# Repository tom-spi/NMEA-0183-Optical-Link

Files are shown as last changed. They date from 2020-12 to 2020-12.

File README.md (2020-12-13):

# NMEA-0183-Optical-Link
FdEng Marine Electrical &amp; Electronic: Final Project. NMEA 0183 multiplexed fiber optic link. 
# Abstract
The standardised protocol between navigation & communication equipment on board merchant vessels is NMEA 0183. The NMEA 0183 protocol utilises the TIA/EIA 422-B serial data standard as its transmission medium [1]. The TIA/EIA 422-B standard (Commonly referred to as RS422), is a balanced double-current interchange circuit that supports data rates of up to 10Mbit/s [2]. The electrical configuration of RS422 employs a matched twisted pair that can support wire lengths of up to 4Km. In practice, shielded data cable (CAT5 STP & above) is commonly employed which offers good noise immunity to some extent. The effective noise immunity and long transmission distances can only be achieved given correct termination and separation from EMI & noise sources. 

On board a vessel, there may be a need to run long lengths of NMEA (or any RS422/485 type protocol) through areas of high EMI or electrical noise. For example, a transducer mounted on the aft of the vessel may have to run its NMEA cable(s) via the engine room to reach the bridge, this may pass through switchboard rooms, converter rooms and may also be run alongside or very close to high voltage conductors. All these areas can pose challenges due to the high levels of electrical noise and EMI. 

Utilising an optical based link means the transmission medium for the NMEA data is completely immune to any sources of noise, meaning the optical cable can be run alongside any other conductor. This can reduce costs by eliminating the need for extra deck/bulkhead penetrations, fire rated glands and additional time needed to implement the segregation of power and data conductors. Along with this, the fibre can be used as a “backbone”, carrying multiple NMEA sentences down a single fibre, eliminating the need to run multiple fibres or multiple STP cables. This can be particularly useful in a situation where there is a cluster of NMEA devices located a considerable distance from the bridge (i.e. up forward or up mast). Additionally, there is no possibility of ground loops across the optical link and the NMEA devices at each end of the optical link can be considered to be optically isolated from one another.

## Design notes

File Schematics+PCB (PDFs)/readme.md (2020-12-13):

Folder contains pdf files of schematics and PCB layers for all PCBs.

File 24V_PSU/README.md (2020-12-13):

An isolated 24v PSU was assembled utilising an off the shelf isolated power supply module.

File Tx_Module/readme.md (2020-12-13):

This folder contains the KiCAD files, PCB Gerber files and software written for the Tx Module.

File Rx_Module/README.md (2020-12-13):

This folder contains the KiCAD files, PCB Gerber files and software written for the Rx Module.

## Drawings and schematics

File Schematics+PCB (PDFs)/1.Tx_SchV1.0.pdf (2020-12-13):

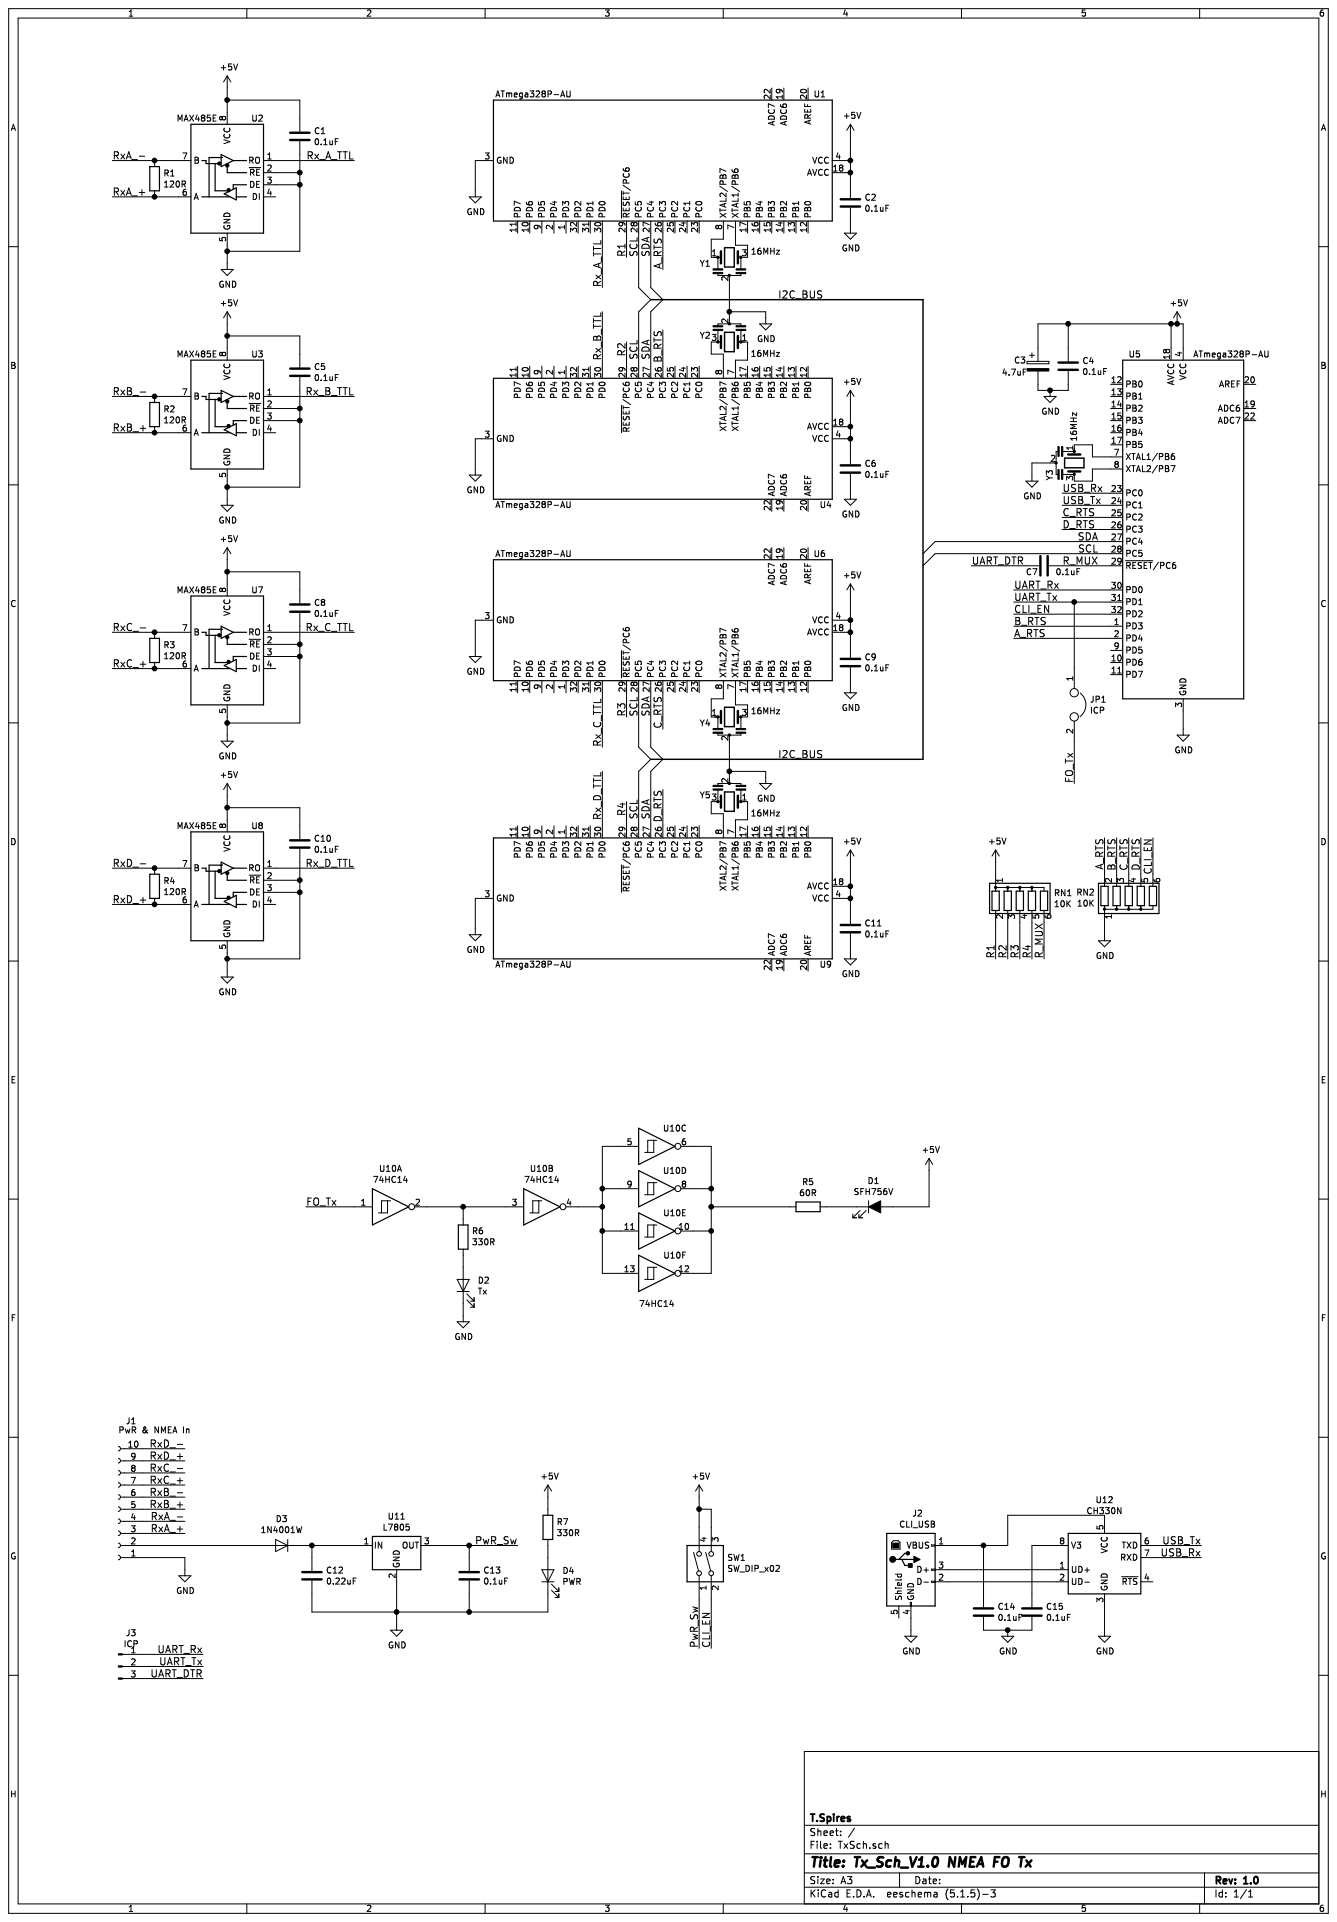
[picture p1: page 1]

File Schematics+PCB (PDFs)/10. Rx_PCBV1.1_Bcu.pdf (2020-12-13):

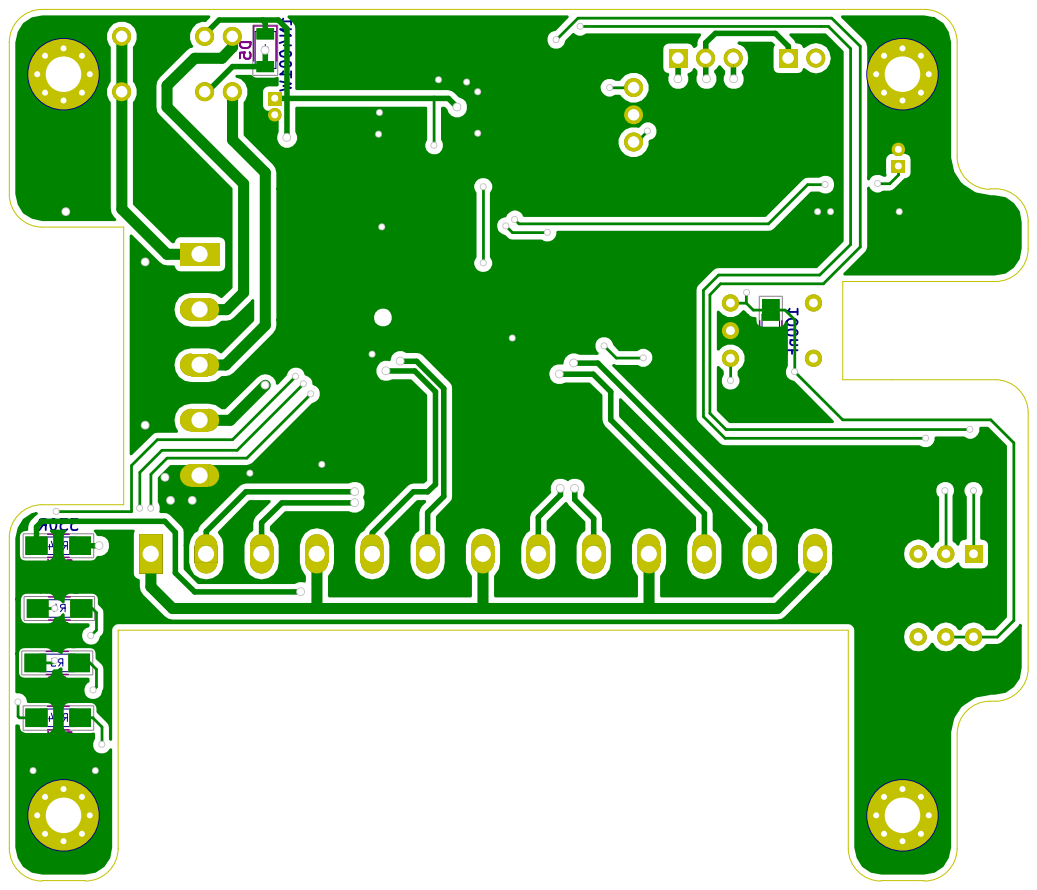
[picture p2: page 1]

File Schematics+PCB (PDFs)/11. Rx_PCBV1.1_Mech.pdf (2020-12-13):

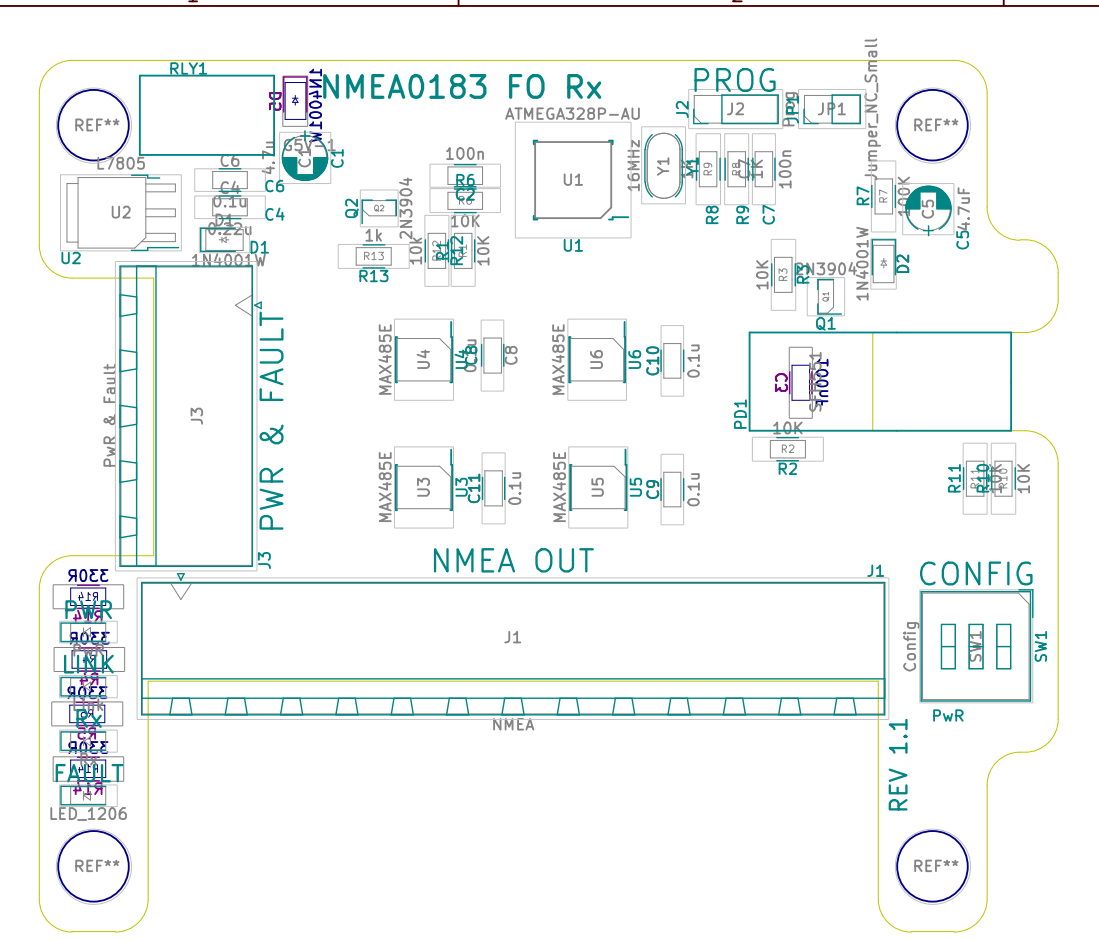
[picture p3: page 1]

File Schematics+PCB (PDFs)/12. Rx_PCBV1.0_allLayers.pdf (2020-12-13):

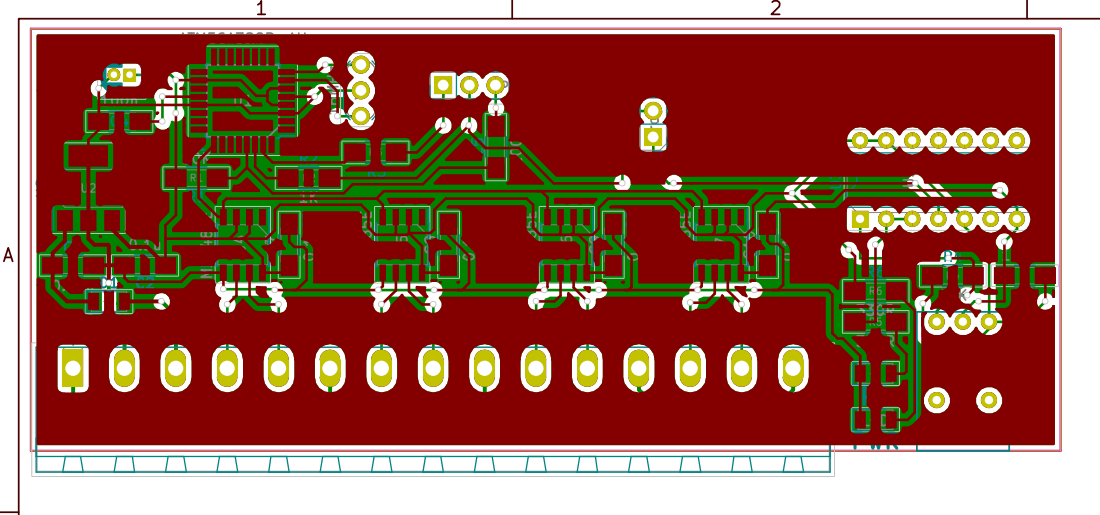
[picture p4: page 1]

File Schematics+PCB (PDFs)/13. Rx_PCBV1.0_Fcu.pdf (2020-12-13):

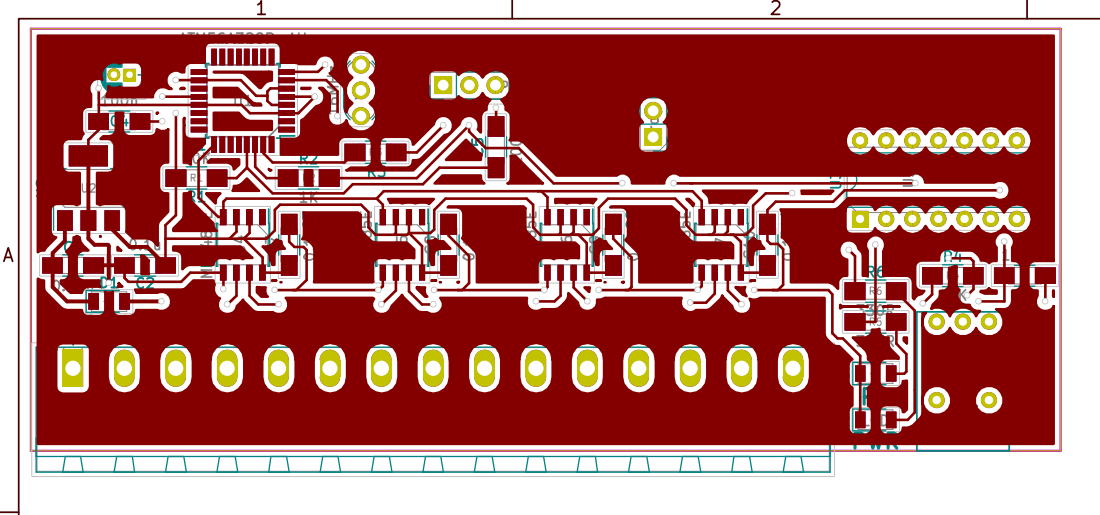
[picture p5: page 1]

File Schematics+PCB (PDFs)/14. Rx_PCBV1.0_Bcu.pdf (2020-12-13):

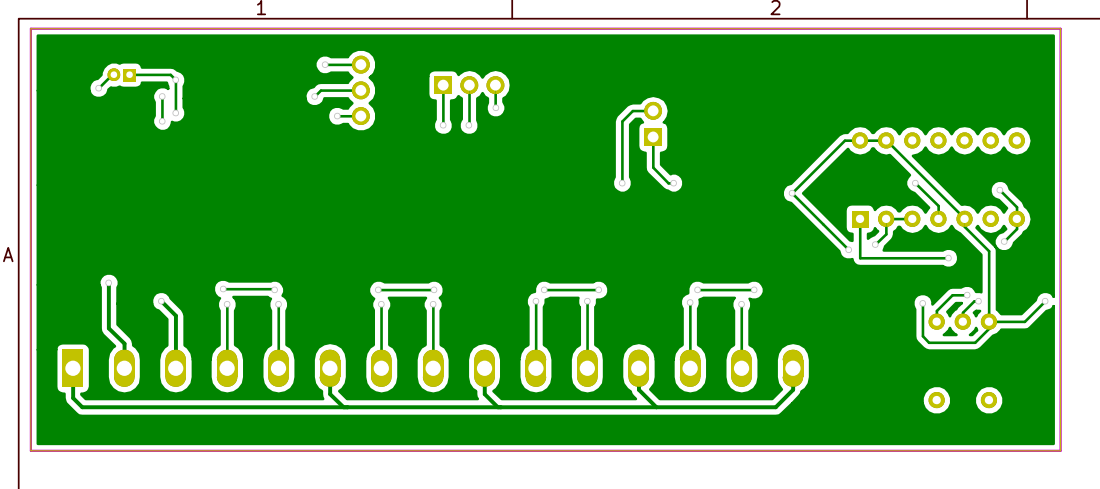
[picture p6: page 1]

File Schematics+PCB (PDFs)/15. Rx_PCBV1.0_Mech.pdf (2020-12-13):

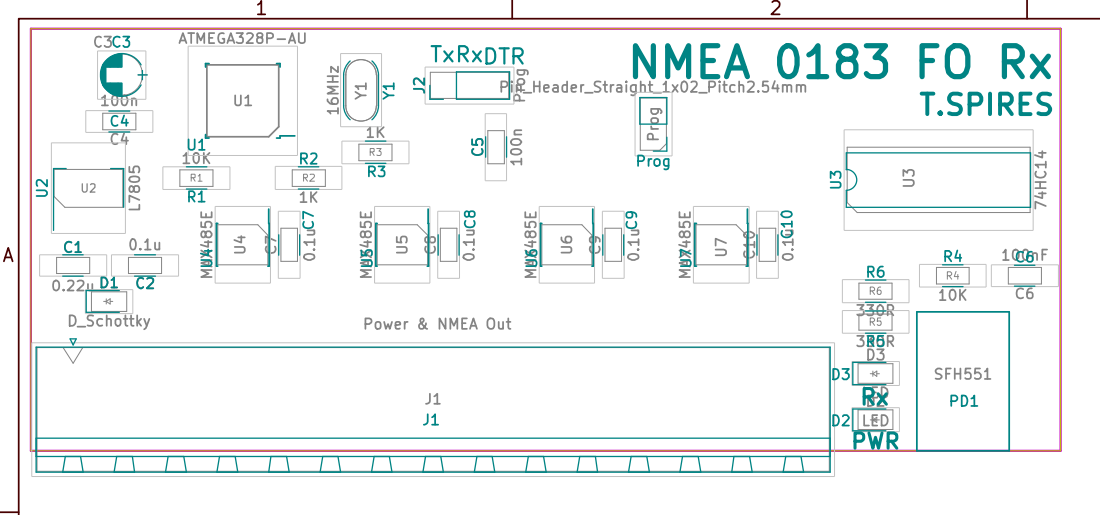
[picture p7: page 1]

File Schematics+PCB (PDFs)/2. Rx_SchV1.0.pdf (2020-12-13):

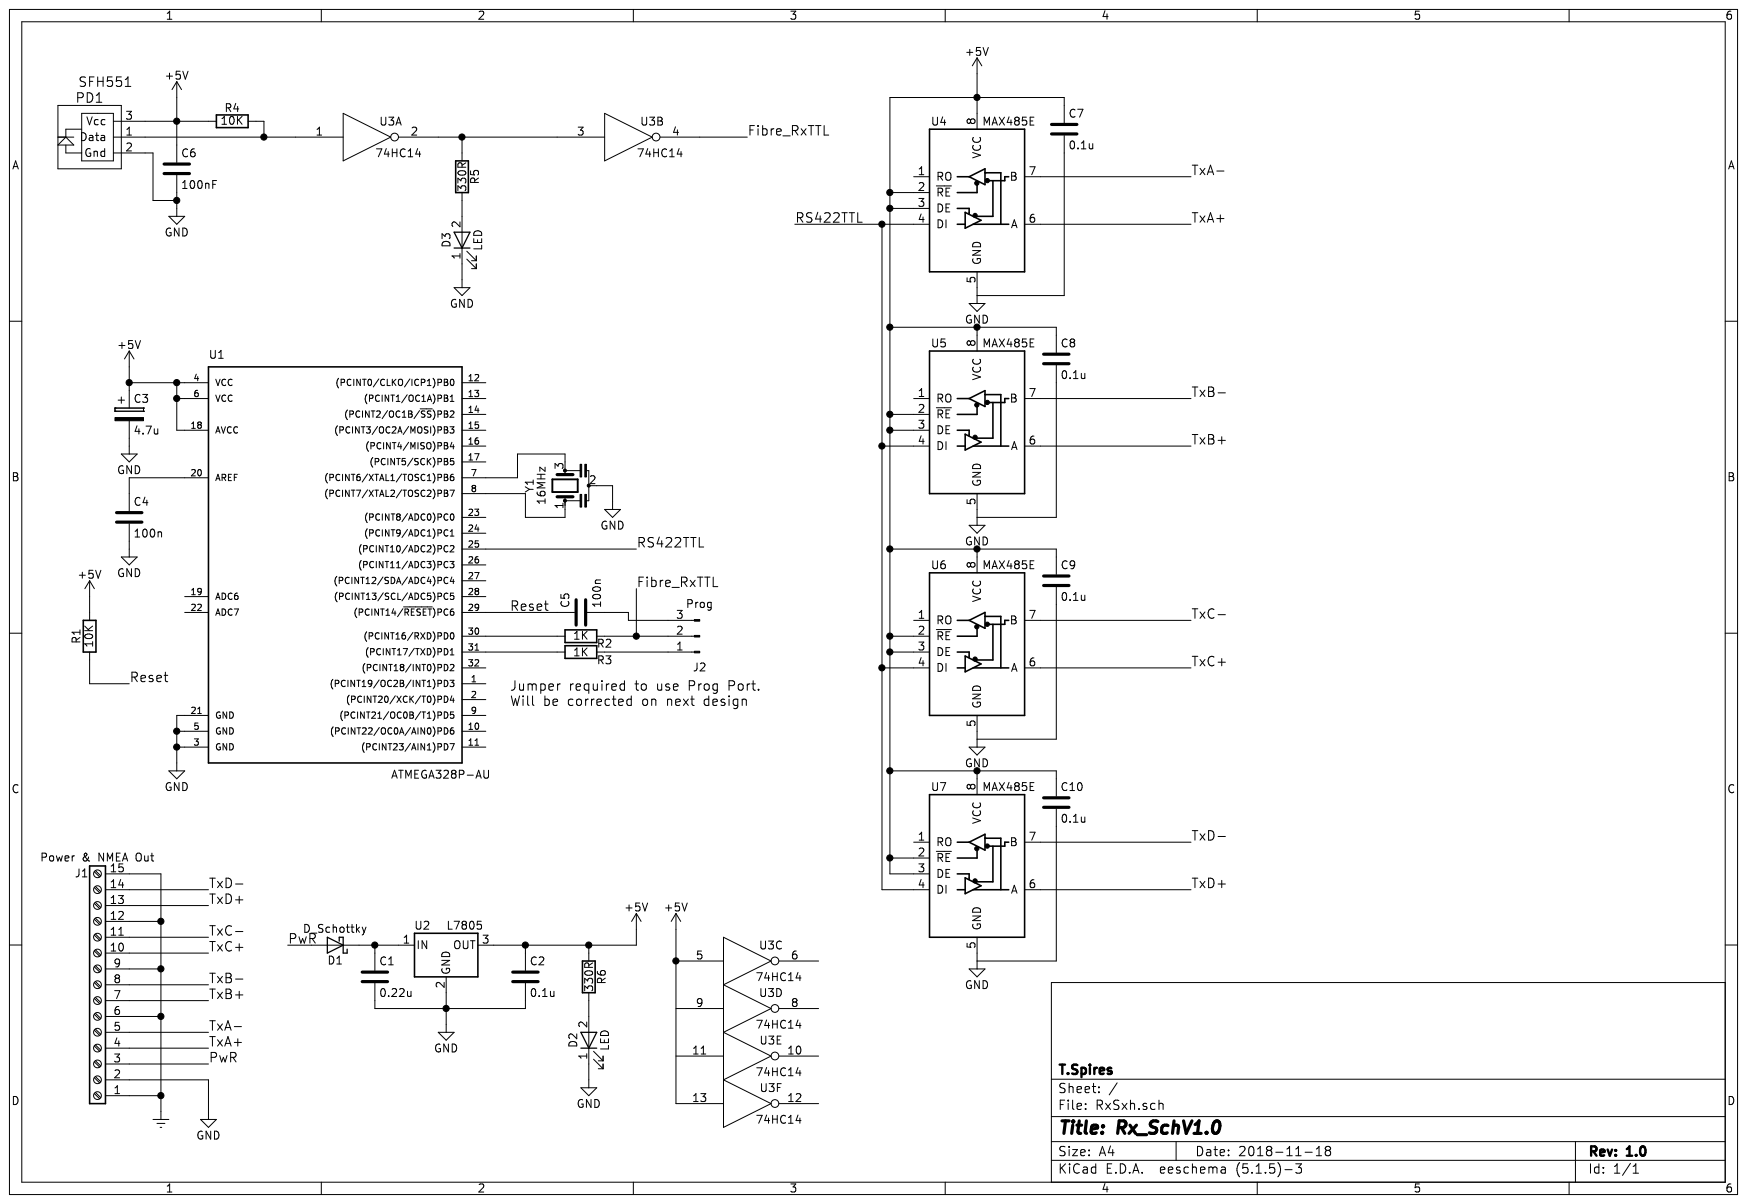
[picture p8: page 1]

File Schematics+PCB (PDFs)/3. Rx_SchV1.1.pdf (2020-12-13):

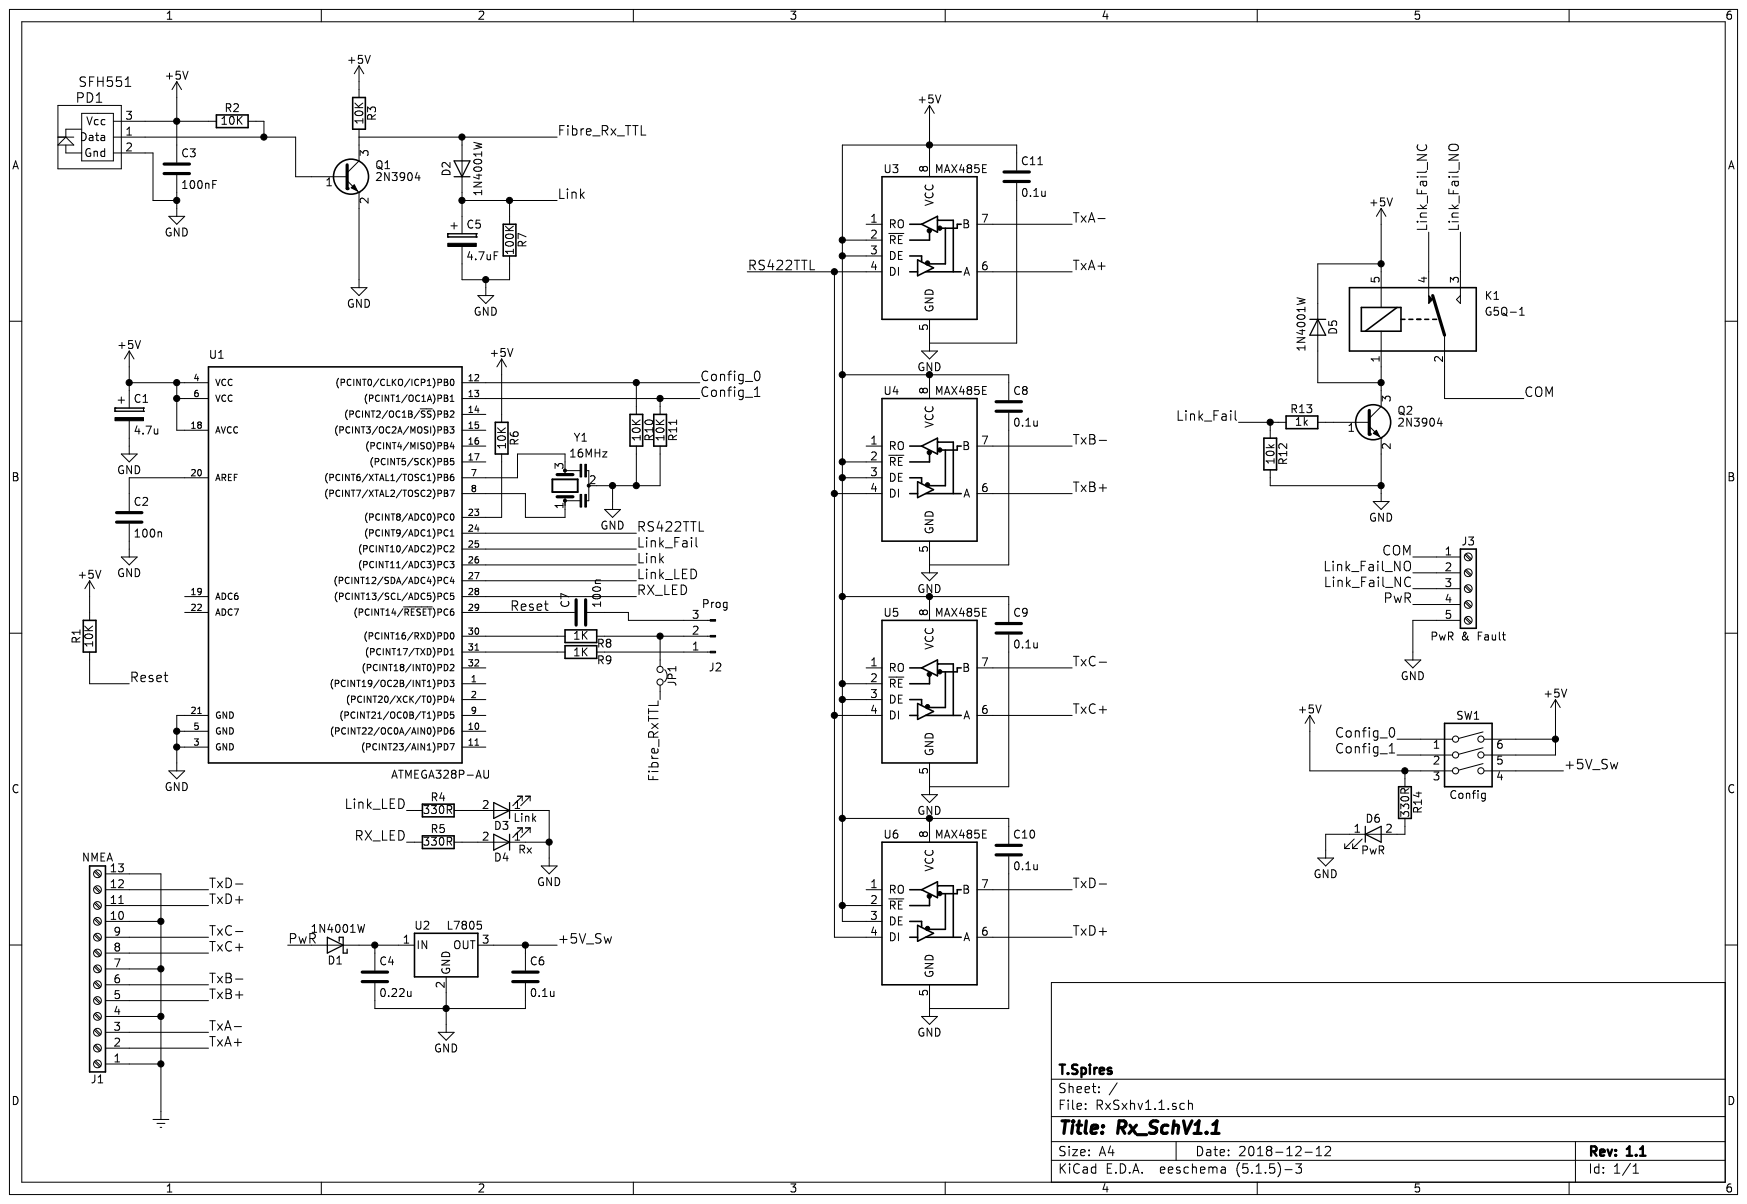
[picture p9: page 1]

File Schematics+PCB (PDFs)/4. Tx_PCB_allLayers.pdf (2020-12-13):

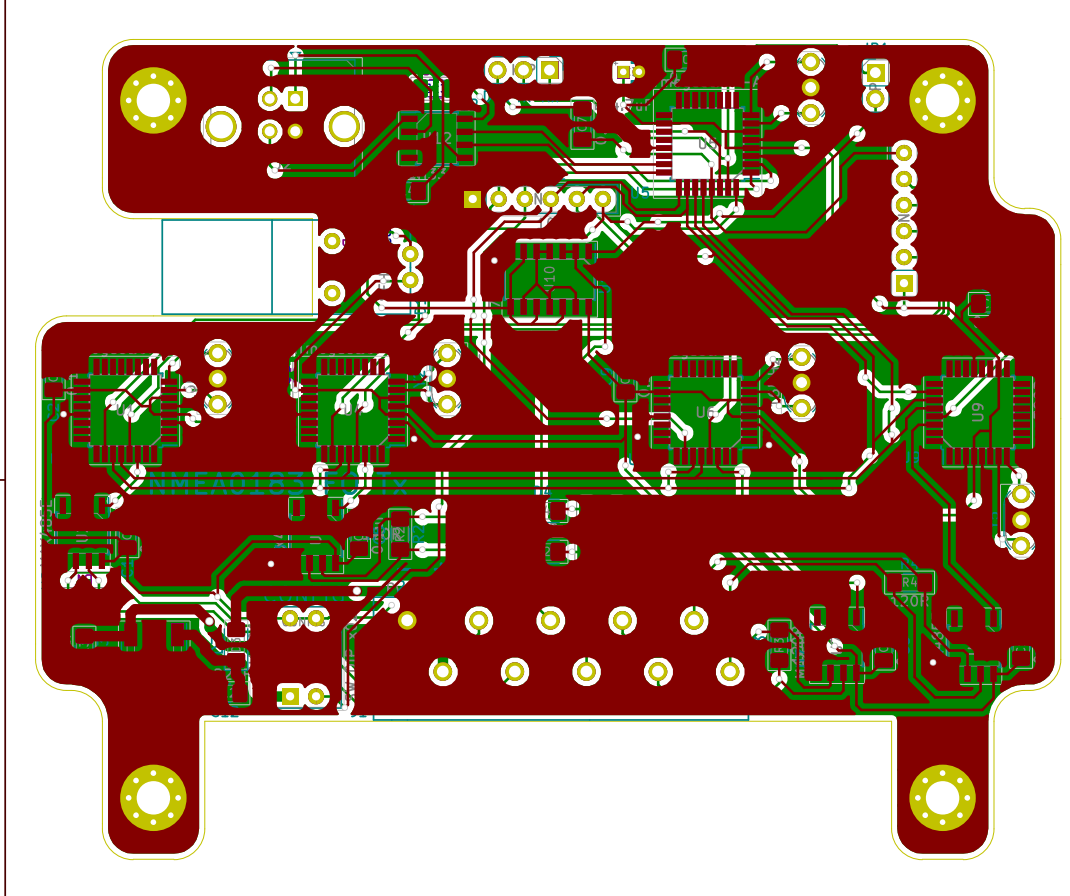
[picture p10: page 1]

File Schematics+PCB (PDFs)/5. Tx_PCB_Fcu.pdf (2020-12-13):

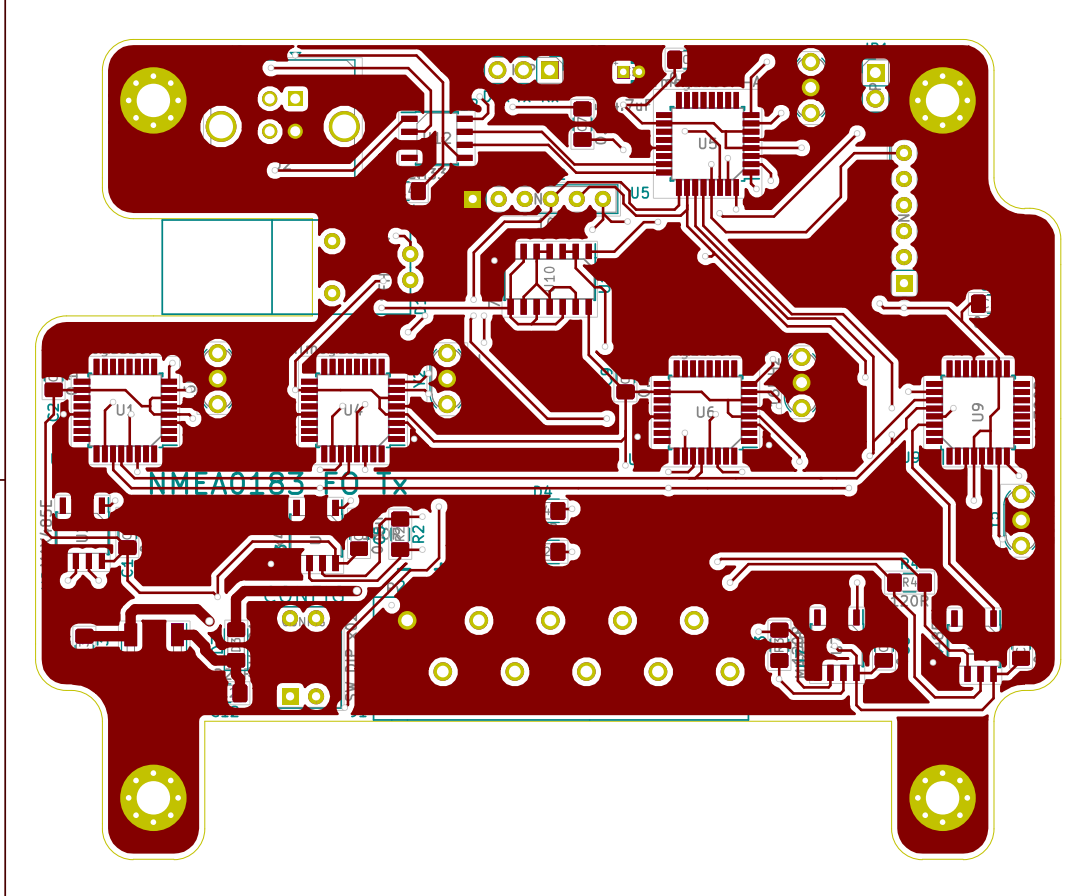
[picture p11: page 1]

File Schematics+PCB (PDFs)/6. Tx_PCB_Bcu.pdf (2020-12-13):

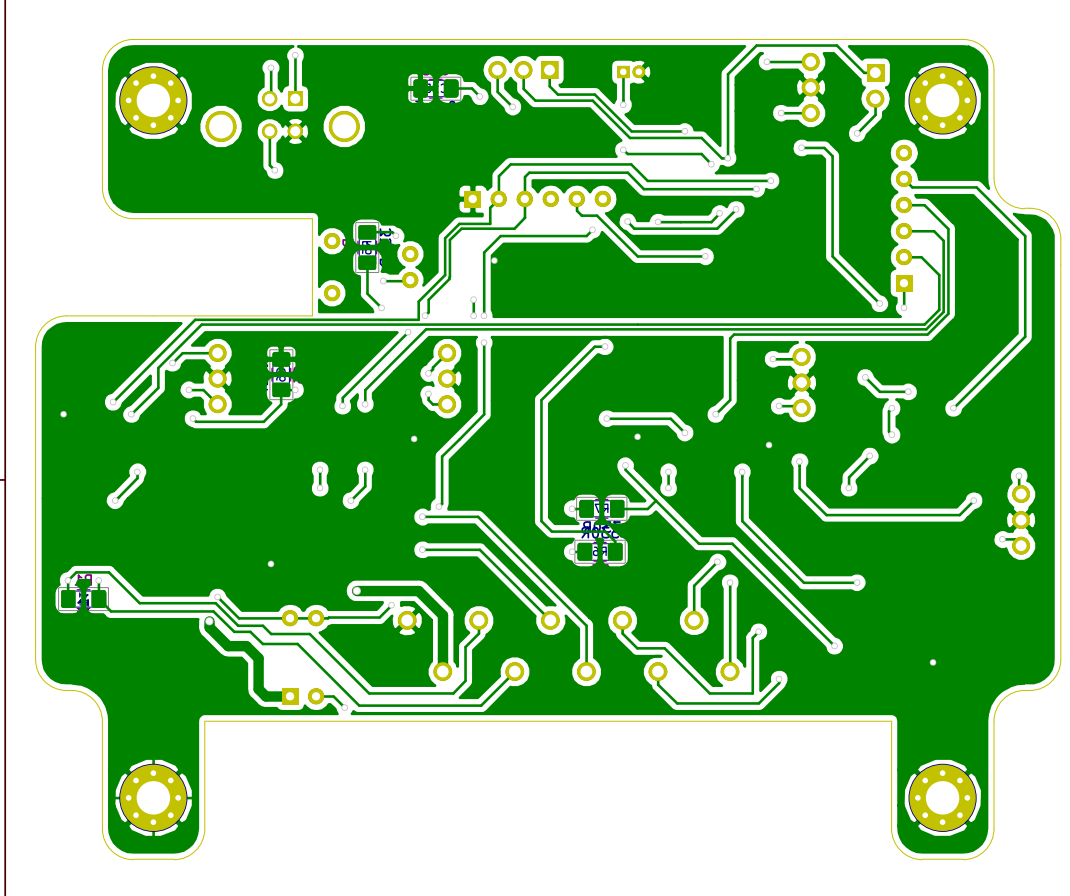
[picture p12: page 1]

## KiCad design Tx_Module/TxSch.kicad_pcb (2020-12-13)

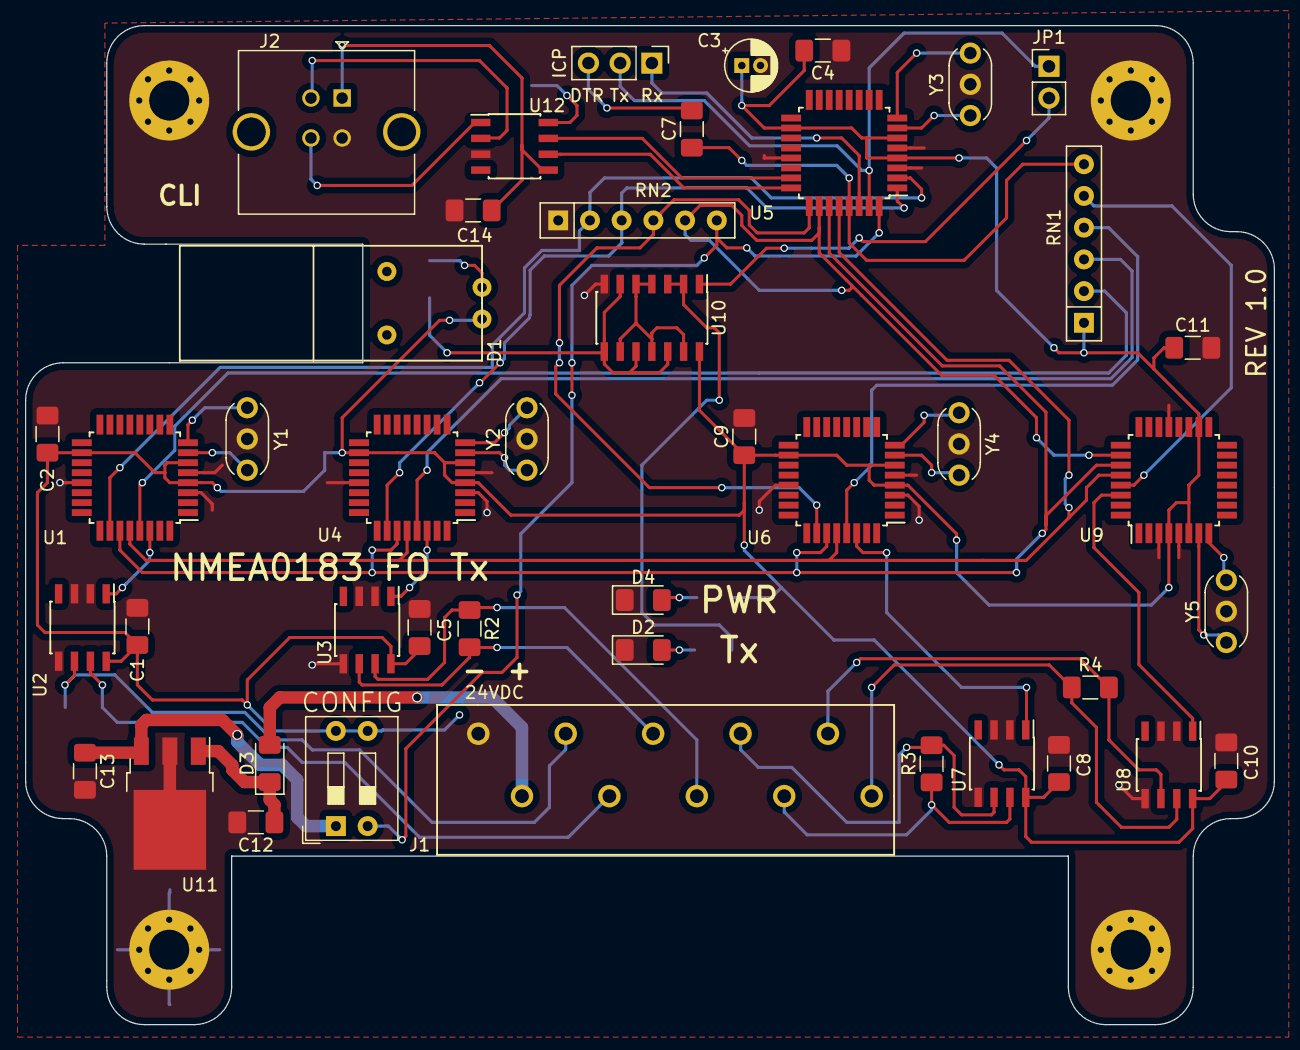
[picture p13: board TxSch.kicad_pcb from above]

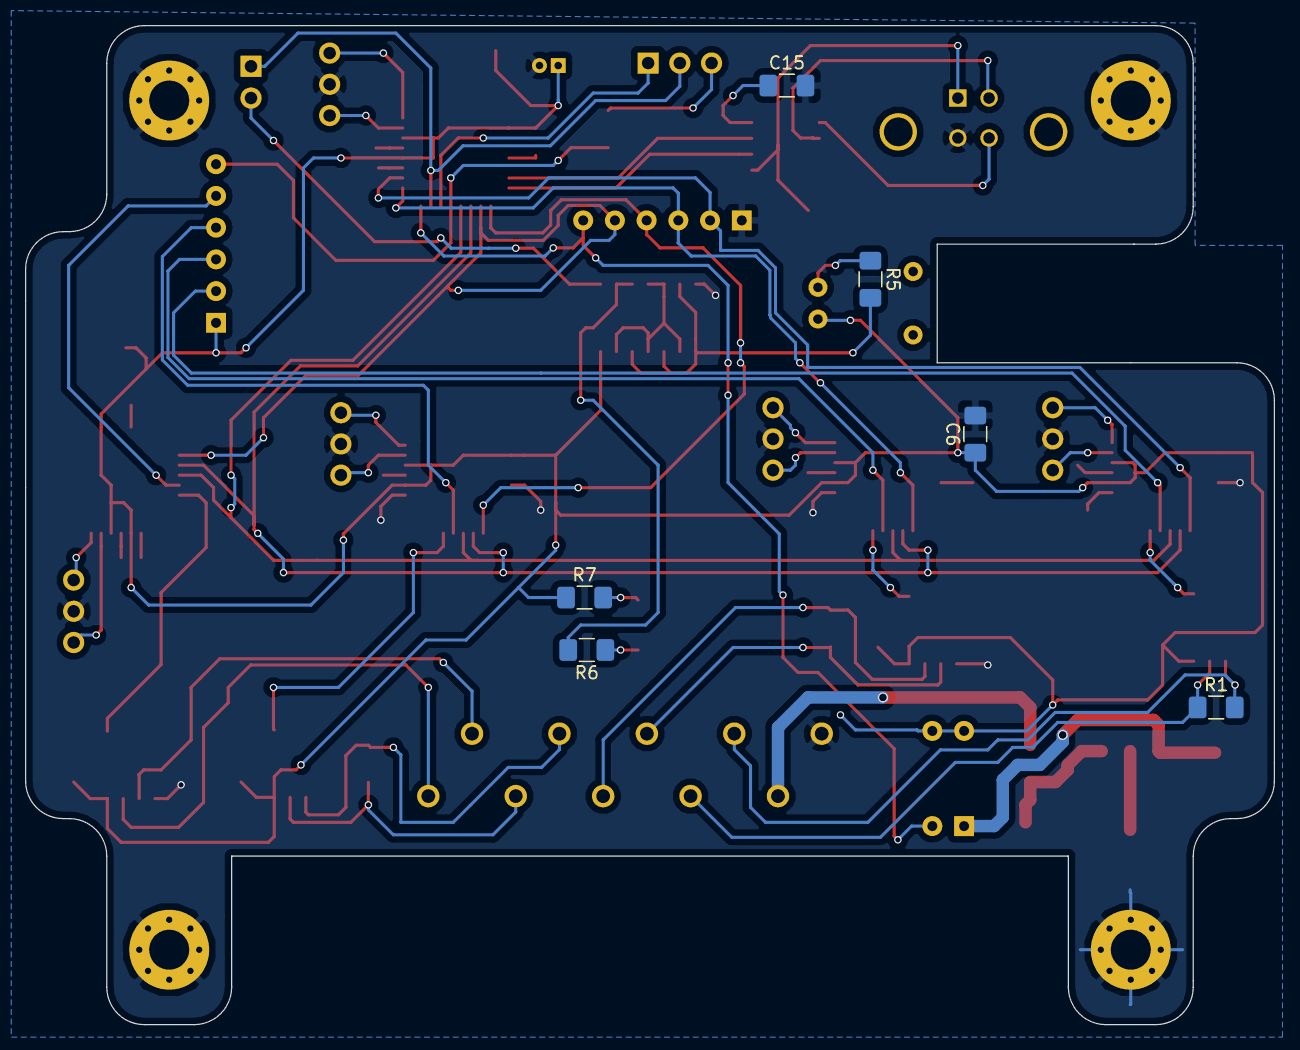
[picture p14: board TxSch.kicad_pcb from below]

Board: 2 copper layers, 100.0 x 80.0 mm, 50 parts (6 on the bottom side), 55 nets.

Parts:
C1, C2, C4, C5, C6, C7, C8, C9, C10, C11, C13, C14, C15: 0.1uF; C_1206_3216Metric_Pad1.42x1.75mm_HandSolder
C3: 4.7uF; CP_Radial_D4.0mm_P1.50mm
C12: 0.22uF; C_1206_3216Metric_Pad1.42x1.75mm_HandSolder
CONFIG: SW_DIP_x02; SW_DIP_SPSTx02_Slide_9.78x7.26mm_W7.62mm_P2.54mm
D1: SFH756V
D2: Tx; LED_1206_3216Metric_Pad1.42x1.75mm_HandSolder
D3: 1N4001W; D_1206_3216Metric_Pad1.42x1.75mm_HandSolder
D4: PWR; LED_1206_3216Metric_Pad1.42x1.75mm_HandSolder
ICP: ICP; PinHeader_1x03_P2.54mm_Vertical
J1: PwR & NMEA In; 10PPush_in_Conn
J2: CLI_USB; USB_B_TE_5787834_Vertical
JP1: ICP; PinHeader_1x02_P2.54mm_Vertical
R1, R2, R3, R4: 120R; R_1206_3216Metric_Pad1.42x1.75mm_HandSolder
R5, R6, R7: 330R; R_1206_3216Metric_Pad1.42x1.75mm_HandSolder
RN1, RN2: 10K; R_Array_SIP6
U1, U4, U5, U6, U9: ATmega328P-AU; TQFP-32_7x7mm_P0.8mm
U2, U3, U7, U8: MAX485E; SOIC-8_3.9x4.9mm_P1.27mm
U10: 74HC14; SOIC-14_3.9x8.7mm_P1.27mm
U11: L7805; TO-252-3_TabPin2
U12: CH330N; SOIC-8_3.9x4.9mm_P1.27mm
Y1, Y2, Y3, Y4, Y5: 16MHz; Resonator-3Pin_W6.0mm_H3.0mm

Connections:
+5V: C1.1, C2.1, C3.1, C4.1, C5.1, C6.1, C8.1, C9.1, C10.1, C11.1, CONFIG.3, CONFIG.4, D1.2, R7.1, RN1.1, U1.4, U1.6, U1.18, U2.8, U3.8, U4.4, U4.6, U4.18, U5.4, U5.6, U5.18, U6.4, U6.6, U6.18, U7.8, U8.8, U9.4, U9.6, U9.18, U10.14
/A_RTS: RN2.2, U1.26, U5.2
/B_RTS: RN2.3, U4.26, U5.1
/CLI_EN: CONFIG.2, RN2.6, U5.32
/C_RTS: RN2.4, U5.25, U6.26
/D_RTS: RN2.5, U5.26, U9.26
/FO_Tx: JP1.2, U10.1
/PwR_Sw: C13.1, CONFIG.1, U11.3
/R1: RN1.2, U1.29
/R2: RN1.3, U4.29
/R3: RN1.4, U6.29
/R4: RN1.5, U9.29
/R_MUX: C7.1, RN1.6, U5.29
/RxA_+: J1.3, R1.2, U2.6
/RxA_-: J1.4, R1.1, U2.7
/RxB_+: J1.5, R2.2, U3.6
/RxB_-: J1.6, R2.1, U3.7
/RxC_+: J1.7, R3.2, U7.6
/RxC_-: J1.8, R3.1, U7.7
/RxD_+: J1.9, R4.2, U8.6
/RxD_-: J1.10, R4.1, U8.7
/Rx_A_TTL: U1.30, U2.1
/Rx_B_TTL: U3.1, U4.30
/Rx_C_TTL: U6.30, U7.1
/Rx_D_TTL: U8.1, U9.30
/SCL: U1.28, U4.28, U5.28, U6.28, U9.28
/SDA: U1.27, U4.27, U5.27, U6.27, U9.27
/UART_DTR: C7.2, ICP.3
/UART_Rx: ICP.1, U5.30
/UART_Tx: ICP.2, JP1.1, U5.31
/USB_Rx: U5.23, U12.7
/USB_Tx: U5.24, U12.6
GND: C1.2, C2.2, C3.2, C4.2, C5.2, C6.2, C8.2, C9.2, C10.2, C11.2, C12.2, C13.2, C14.2, C15.2, D2.1, D4.1, J1.1, J2.4, RN2.1, U1.3, U1.5, U1.21, U2.2, U2.3, U2.5, U3.2, U3.3, U3.5, U4.3, U4.5, U4.21, U5.3, U5.5, U5.21, U6.3, U6.5, U6.21, U7.2, U7.3, U7.5, U8.2, U8.3, U8.5, U9.3, U9.5, U9.21, U10.7, U11.2, U12.3, Y1.2, Y2.2, Y3.2, Y4.2, Y5.2
unnamed: C12.1, D3.1, U11.1
unnamed: C14.1, J2.1, U12.5
unnamed: C15.1, U12.8
unnamed: D1.1, R5.1
unnamed: D2.2, R6.1
unnamed: D3.2, J1.2
unnamed: D4.2, R7.2
unnamed: J2.2, U12.2
unnamed: J2.3, U12.1
unnamed: R5.2, U10.6, U10.8, U10.10, U10.12
unnamed: R6.2, U10.2, U10.3
unnamed: U1.7, Y1.3
unnamed: U1.8, Y1.1
unnamed: U4.7, Y2.1
unnamed: U4.8, Y2.3
unnamed: U5.7, Y3.1
unnamed: U5.8, Y3.3
unnamed: U6.7, Y4.3
unnamed: U6.8, Y4.1
unnamed: U9.7, Y5.1
unnamed: U9.8, Y5.3
unnamed: U10.4, U10.5, U10.9, U10.11, U10.13

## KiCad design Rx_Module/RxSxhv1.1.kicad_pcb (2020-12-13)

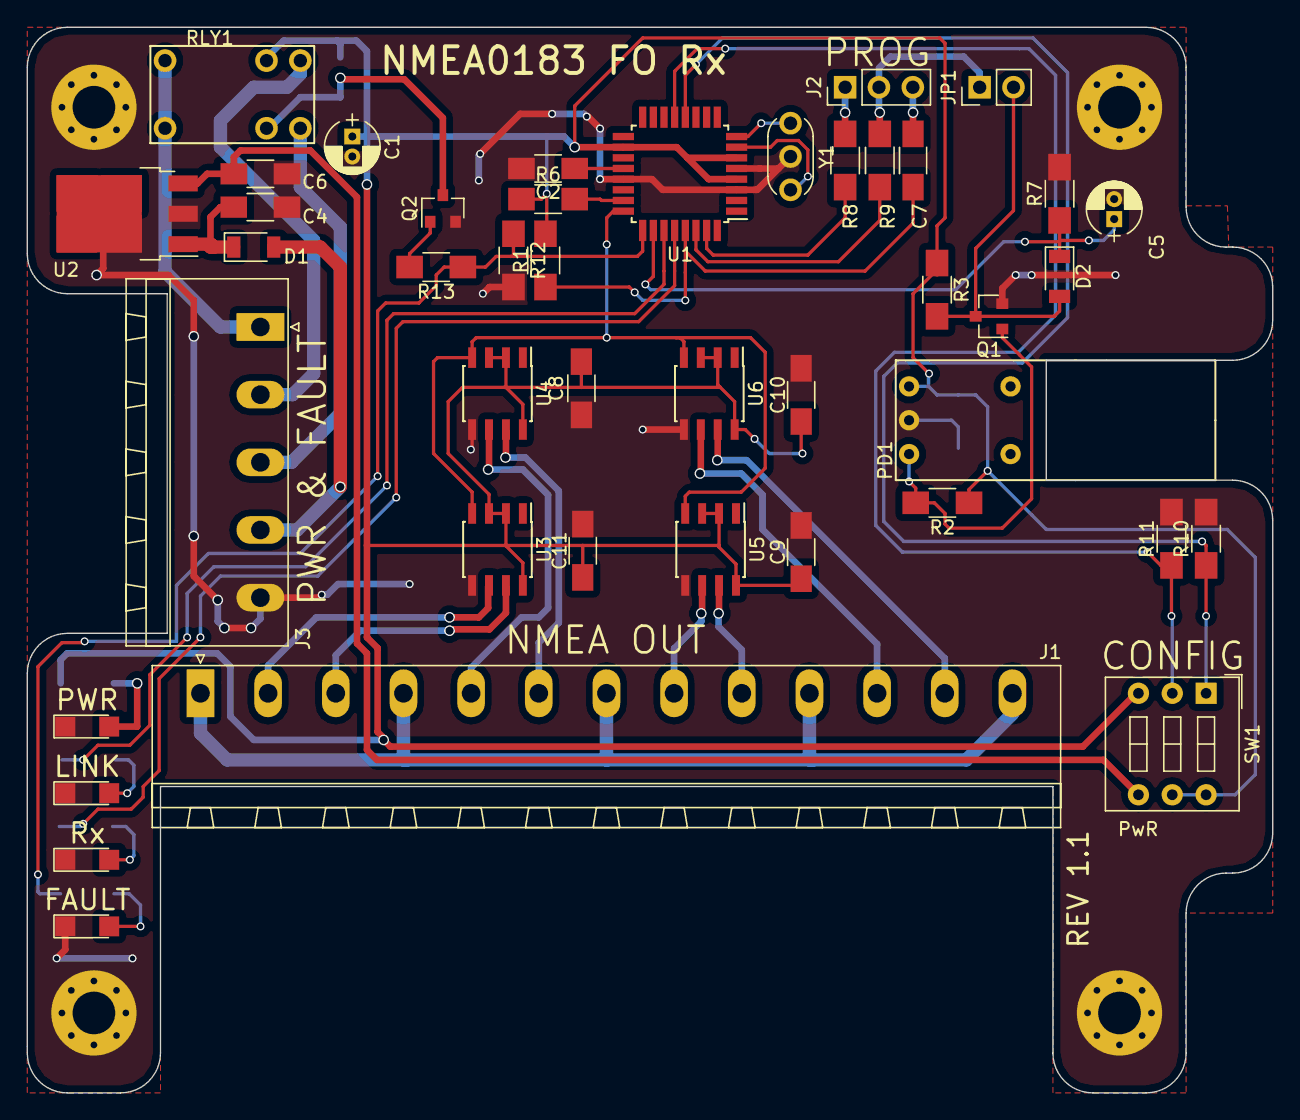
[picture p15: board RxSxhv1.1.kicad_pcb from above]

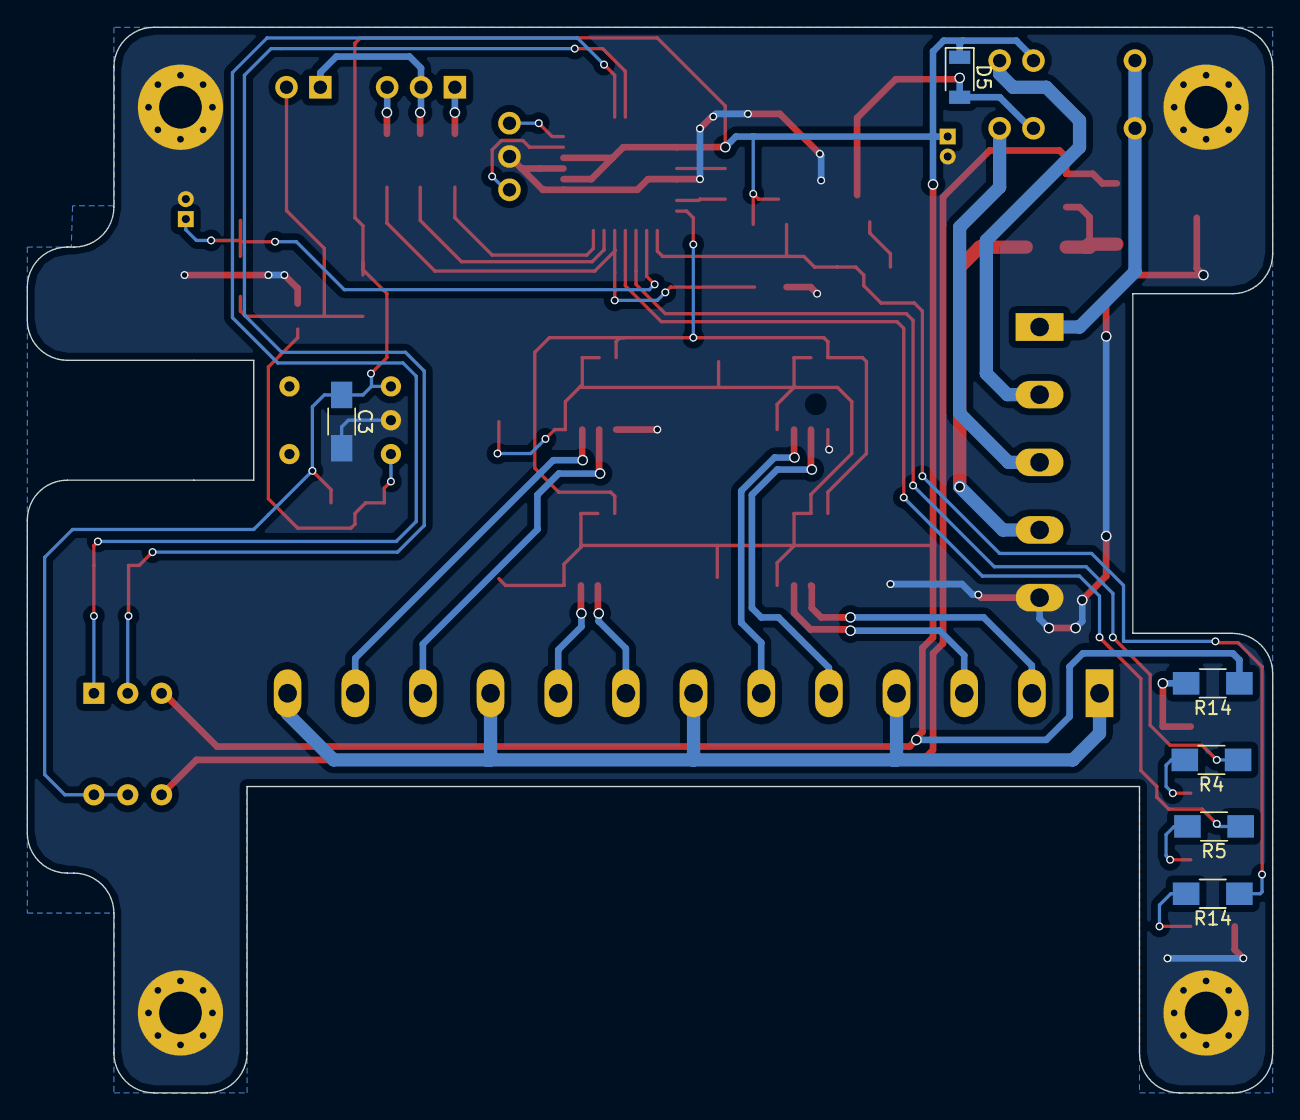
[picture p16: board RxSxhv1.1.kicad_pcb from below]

Board: 2 copper layers, 93.5 x 80.0 mm, 49 parts (6 on the bottom side), 41 nets.

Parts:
C1: 4.7u; CP_Radial_D4.0mm_P1.50mm
C2, C7: 100n; C_1206_HandSoldering
C3: 100nF; C_1206_HandSoldering
C4: 0.22u; C_1206_HandSoldering
C5: 4.7uF; CP_Radial_D4.0mm_P1.50mm
C6, C8, C9, C10, C11: 0.1u; C_1206_HandSoldering
D1, D2, D5: 1N4001W; D_1206
FAULT: LED_1206
J1: NMEA; PhoenixContact_MSTBA-G_13x5.08mm_Angled
J2: Prog; Pin_Header_Straight_1x03_Pitch2.54mm
J3: PwR & Fault; PhoenixContact_MSTBA-G_05x5.08mm_Angled
JP1: Jumper_NC_Small; Pin_Header_Straight_1x02_Pitch2.54mm
LINK: Link; LED_1206
PD1: SFH551
PWR: PwR; LED_1206
Q1, Q2: 2N3904; SOT-23
R1, R2, R3, R6, R10, R11: 10K; R_1206_HandSoldering
R4, R5, R14, R14#2: 330R; R_1206_HandSoldering
R7: 100K; R_1206_HandSoldering
R8, R9: 1K; R_1206_HandSoldering
R12: 10k; R_1206_HandSoldering
R13: 1k; R_1206_HandSoldering
RLY1: G5V-1
Rx: Rx; LED_1206
SW1: Config; SW_DIP_x3_W7.62mm_Slide
U1: ATMEGA328P-AU; TQFP-32_7x7mm_Pitch0.8mm
U2: L7805; TO-252-3_TabPin4
U3, U4, U5, U6: MAX485E; SOIC-8_3.9x4.9mm_Pitch1.27mm
Y1: 16MHz; Resonator-3pin_w6.0mm_h3.0mm

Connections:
+5V: C1.1, C3.1, C8.1, C9.1, C10.1, C11.1, D5.1, PD1.3, R1.2, R2.1, R3.1, R6.1, R14#2.1, RLY1.4, SW1.3, SW1.5, SW1.6, U1.4, U1.6, U1.18, U3.2, U3.3, U3.8, U4.2, U4.3, U4.8, U5.2, U5.3, U5.8, U6.2, U6.3, U6.8
/+5V_Sw: C6.1, SW1.4, U2.3
/COM: J3.1, RLY1.5, RLY1.6
/Config_0: R10.1, SW1.1, U1.12
/Config_1: R11.1, SW1.2, U1.13
/Fibre_Rx_TTL: D2.2, JP1.2, Q1.3, R3.2
/Link: C5.1, D2.1, R7.1, U1.26
/Link_Fail: R12.1, R13.1, R14.1, U1.25
/Link_Fail_NC: J3.3, RLY1.2
/Link_Fail_NO: J3.2, RLY1.1
/Link_LED: R4.1, U1.27
/PwR: D1.2, J3.4
/RS422TTL: U1.24, U3.4, U4.4, U5.4, U6.4
/RX_LED: R5.1, U1.28
/Reset: C7.1, R1.1, U1.29
/TxA+: J1.2, U3.6
/TxA-: J1.3, U3.7
/TxB+: J1.5, U4.6
/TxB-: J1.6, U4.7
/TxC+: J1.8, U5.6
/TxC-: J1.9, U5.7
/TxD+: J1.11, U6.6
/TxD-: J1.12, U6.7
Earth: J1.1, J1.4, J1.7, J1.10, J1.13
GND: C1.2, C2.2, C3.2, C4.2, C5.2, C6.2, C8.2, C9.2, C10.2, C11.2, FAULT.1, J3.5, LINK.1, PD1.2, PWR.1, Q1.2, Q2.2, R7.2, R10.2, R11.2, R12.2, Rx.1, U1.3, U1.5, U1.21, U2.2, U2.4, U3.5, U4.5, U5.5, U6.5, Y1.2
unnamed: C2.1, U1.20
unnamed: C4.1, D1.1, U2.1
unnamed: C7.2, J2.3
unnamed: LINK.2, R4.2
unnamed: R5.2, Rx.2
unnamed: D5.2, Q2.3, RLY1.3
unnamed: PWR.2, R14#2.2
unnamed: J2.1, R9.1
unnamed: J2.2, JP1.1, R8.2
unnamed: PD1.1, Q1.1, R2.2
unnamed: Q2.1, R13.2
unnamed: R6.2, U1.23
unnamed: R8.1, U1.30
unnamed: R9.2, U1.31
unnamed: U1.7, Y1.3
unnamed: U1.8, Y1.1

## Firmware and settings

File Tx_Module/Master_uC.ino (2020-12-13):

/*
|--------------------------------------------------------------------------------------------|
|                        --NMEA 0183 OPTICAL LINK Tx MODULE--                                |
|                                                                                            |
|                                                                                            |
|  Project          NMEA_FO.proj                                                             |
|  Program Name 	Tx_Master_v1.01.ino                                                      |
|  Author			Thomas Spires 															 |
|															                                 |
|  Author Info:                                                                              |
|  Firmware to be written to U5 (ATMEGA328P) on Tx PCB: refer to KiCAD .kicad_pcb            |
|  "TxSch.kicad_pcb"                 USRNOTE:** U5 TO BE PROGRAMMED OFF BOARD  **            |
|                                                                                            |
|  Revision Release Info:                                                                    |
|  20181216 02:12    Tspires      1.0      Initial Deployment with No configuration ability  |
|  20190126 22:43    Tspires      1.01     Added Configuration ability to be used in         |
|										   conjunction with VB config application            |
|										   "NMEA FO Link Config.exe"                         |
|--------------------------------------------------------------------------------------------|
*/ 
                 

#include <Wire.h>							//include Microchip I2C hex files to set I2C registers
#include <EEPROM.h>							//include Microchip on-chip EEPROM hex files to configure memory map for configuration options
#include <SoftwareSerial.h>					//include Bit-Banged serial port hex files

SoftwareSerial USB_ConfigSerial(A1, A0); 	// RX, TX // Set BitBanged serial port registers accordingly

// Declare Global Variables

int addr = 0;									//Initialise intiger vairble to hold channel addresses				
byte config_val;								//Initialise a variable to read config EEPROM and pass via i2c on boot
char rx_byte;									//Initialise ASCII Char byte to be passed via i2c
int config_data = 0;							//Initialise variable to store incoming USB configuration 
bool tx_debug = false;							//Initialise a flag to enable NMEA Sentence output over USB	

// Declare Pin Names

#define Ch_A_BufferFlag 4
#define Ch_B_BufferFlag 3
#define Ch_C_BufferFlag A2
#define Ch_D_BufferFlag A3
#define Config_Mode_Sw 2										

//Initialise Registers & Interfaces

void setup() {
  //Initialise UARTs
  Serial.begin(19200);							//Start hardware UART & set registers for 19200 Baud. 
  USB_ConfigSerial.begin(9600);  				//Start bitbanged UART & set registers for 9600 Baud
  //Set GPIO Registers
  pinMode(Ch_A_BufferFlag, INPUT); 				//Channel A Buffer Flag Input !! I2C addr 0 !!
  pinMode(Ch_B_BufferFlag, INPUT); 				//Channel B Buffer Flag Input !! I2C addr 1 !!
  pinMode(Ch_C_BufferFlag, INPUT); 				//Channel C Buffer Flag Input !! I2C addr 2 !!
  pinMode(Ch_D_BufferFlag, INPUT); 				//Channel D Buffer Flag Input !! I2C addr 3 !!
  pinMode(Config_Mode_Sw, INPUT); 				//Configuration Mode Enable DIP Sw
  //Initialise I2C
  Wire.begin();        							//Initialise I2C Interface, join bus as master (no address)
  delay (10);									/*Perform a 10ms delay before sending channel configurations over I2C
  												Gives time for channel uCs to boot, join I2C Bus and begin listening*/
  send_config();									
}

//Send Config Data on bootup

void send_config() {					//Function when called, will transmit configuration bytes to each channel via I2C
  for (addr = 0; addr <= 3; addr++){    //Loop Through all channel addresses
    config_val = EEPROM.read(addr);		//load configuration value from EEPROM address based on i2c channel address into config_val
    Wire.beginTransmission(addr);		//Set i2c Tx Registers to intended address
    Wire.write(config_val);             //Transmitt config_val via I2C to channel *SENDING CONFIGURATION DATA HERE*
    Wire.endTransmission();				//Reset i2c Registers and idle interface
  }
}

// Function called on address buffer flag 'HIGH' detected

void Readbuffer_Tx() {										/*Function when called, will read contents of channel buffer
															   and transmit down out hardware UART to Fibre LED */ 
  while ((Wire.available() > 0) && (tx_debug == false)) { 	//Wait for I2C Slave on channel to Tx (may send less than requested (>0))
    rx_byte = Wire.read();									//Read Tx'd byte from channel over I2C & store into rx_byte
    Serial.print(rx_byte);									//Transmit the byte over the Fibre UART at 19200 Baud
    if (rx_byte == '\n') {									//When the end of the NMEA sentence is detected, break from function
      break;
      }
   }

while ((Wire.available() > 0) && (tx_debug == true)) { 		/*Function when called, will read contents of channel buffer
															   and transmit down out hardware UART to Fibre LED. 
															   Will also transmit over USB to PC config tool */ 
	rx_byte = Wire.read();							   		//Wait for I2C Slave on channel to Tx (may send less than requested (>0))
	Serial.print(rx_byte);									//Transmit the byte over the Fibre UART at 19200 Baud
	USB_ConfigSerial.print(rx_byte);						//Transmit the byte over the USB UART
	 if (rx_byte == '\n') {									//When the end of the NMEA sentence is detected, break from function
		break;						
	}
}
}


void loop() {							//Function will loop continuoisly to check status of channel buffer flags
	if (Ch_A_BufferFlag == HIGH) { 		//Buffer Flag 'HIGH' detected on channel A
		Wire.requestFrom(0, 128);		//Transmit i2c poll message to channel A (addr 0), request full buffer (128 bytes)     	
		Readbuffer_Tx();				//Call function to wait for channel i2c transmission, read buffer & send out fibre UART  
	  }
	if (Ch_B_BufferFlag == HIGH) { 		//Buffer Flag 'HIGH' detected on channel B
		Wire.requestFrom(1, 128);    	//Transmit i2c poll message to channel B (addr 1), request full buffer (128 bytes)
		Readbuffer_Tx();				//Call function to wait for channel i2c transmission, read buffer & send out fibre UART  
		}
	if (Ch_C_BufferFlag == HIGH) { 		//Buffer Flag 'HIGH' detected on channel C
		Wire.requestFrom(2, 128);    	//Transmit i2c poll message to channel C (addr 2), request full buffer (128 bytes)
		Readbuffer_Tx();				//Call function to wait for channel i2c transmission, read buffer & send out fibre UART  
	}
	if (Ch_D_BufferFlag == HIGH) { 		//Buffer Flag 'HIGH' detected on channel D
		Wire.requestFrom(3, 128);    	//Transmit i2c poll message to channel C (addr 2), request full buffer (128 bytes)
		Readbuffer_Tx();				//Call function to wait for channel i2c transmission, read buffer & send out fibre UART
	}
	
	//	Below will only run in configuration mode 

	while ((USB_ConfigSerial.available() > 0) && (Config_Mode_Sw == 1) ) {			//If config DIP Sw is set & Data Rx'd on USB
		config_data = USB_ConfigSerial.read();										//Read config byte sent down USB
		//Serial.print(config_data);						//LoopBack Interface Via Optical Link used for debugging
		
		switch (config_data) {
		    case '1' :
		    	USB_ConfigSerial.print("1");					//Transmit a 1 for loopback & allow config software to parse data
				USB_ConfigSerial.println(EEPROM.read(0));		//Read EEPROM Configuration Data for channel A and send over USB
		      break;
		    case '2' :
		    	USB_ConfigSerial.print("2");					//Transmit a 2 for loopback & allow config software to parse data
				USB_ConfigSerial.println(EEPROM.read(1));		//Read EEPROM Configuration Data for channel B and send over U
		      break;
		    case '3' :
		    	USB_ConfigSerial.print("3");					//Transmit a 3 for loopback & allow config software to parse data
				USB_ConfigSerial.println(EEPROM.read(2));		//Read EEPROM Configuration Data for channel C and send over USB
			  break;
			case '4' :
				USB_ConfigSerial.print("4");					//Transmit a 4 for loopback & allow config software to parse data
				USB_ConfigSerial.println(EEPROM.read(3));		//Read EEPROM Configuration Data for channel D and send over USB
			  break;
		}

		if (config_data == 'A') {
			EEPROM.write(0, 1);									//change config val in EEPROM
			//Serial.println("Channel 1 to 2400");
		}
		if (config_data == 'B') {
			EEPROM.write(0, 2);									//change config val in EEPROM
			//Serial.println("Channel 1 to 4800");
		}
		if (config_data == 'C') {
			EEPROM.write(0, 3);									//change config val in EEPROM
			//Serial.println("Channel 1 to 9600");
		}
		if (config_data == 'D') {
			EEPROM.write(0, 4);									//change config val in EEPROM
			//Serial.println("Channel 1 Disabled");
		}
		if (config_data == 'E') {
			EEPROM.write(1, 1);	//change config val
			//Serial.println("Channel 2 to 2400");
		}
		if (config_data == 'F') {
			EEPROM.write(1, 2);	//change config val
			//Serial.println("Channel 2 to 4800");
		}
		if (config_data == 'G') {
			EEPROM.write(1, 3);	//change config val
			//Serial.println("Channel 2 to 9600");
		}
		if (config_data == 'H') {
			EEPROM.write(1, 4);	//change config val
			//Serial.println("Channel 2 Disabled");
		}
		if (config_data == 'I') {
			EEPROM.write(2, 1);	//change config val
			//Serial.println("Channel 3 to 2400");
		}
		if (config_data == 'J') {
			EEPROM.write(2, 2);	//change config val
			//Serial.println("Channel 3 to 4800");
		}
		if (config_data == 'K') {
			EEPROM.write(2, 3);	//change config val
			//Serial.println("Channel 3 to 9600");
		}
		if (config_data == 'L') {
			EEPROM.write(2, 4);	//change config val
			//Serial.println("Channel 3 to DISABLED");
		}
		if (config_data == 'M') {
			EEPROM.write(3, 1);	//change config val
			//Serial.println("Channel 4 to 2400");
		}
		if (config_data == 'N') {
			EEPROM.write(3, 2);	//change config val
			//Serial.println("Channel 4 to 4800");
		}
		if (config_data == 'O') {
			EEPROM.write(3, 3);	//change config val
			//Serial.println("Channel 3 to 9600");
		}
		if (config_data == 'P') {
			EEPROM.write(3, 4);	//change config val
			//Serial.println("Channel 4 to DISABLED");
		}
		if (config_data == 'Y') {
			tx_debug = true;
		}
		if (config_data == 'Z') {
			tx_debug = false;
		}
	}
}

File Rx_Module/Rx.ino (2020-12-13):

/*
|--------------------------------------------------------------------------------------------|
|                        --NMEA 0183 OPTICAL LINK Rx MODULE--                                |
|                                                                                            |
|                                                                                            |
|  Project        NMEA_FO.proj                                                               |
|  Program Name 	Rx_v1.1.ino                                                                |
|  Author		     	Thomas Spires 															                               |
|															                                                               |
|  Author Info:                                                                              |
|  Firmware to be written to U1 (ATMEGA328P) on Rx PCB: refer to KiCAD .kicad_pcb            |
|  "RxPCBV1.1"                                                                               |
|                                                                                            |
|  Revision Release Info:                                                                    |
|  20181210 00:42    Tspires      1.0      Initial Deployment on prototype PCB               |
|  20181219 03:13    Tspires      1.1      Added baud rate config + link status              |
|										   function.                                                             |
|--------------------------------------------------------------------------------------------|
*/

#include <SoftwareSerial.h>					//include Bit-Banged serial port hex files

SoftwareSerial RS422Serial(A0, A1); 		// RX, TX // Set BitBanged serial port registers accordingly

// Declare Global Variables

char rx_byte;								//Initialise ASCII Char byte to be passed from Hardware UART buffer

// Declare Pin Names

#define RX_LED A5
#define Link_LED A4
#define Link_Stat A3
#define Link_Fail A2
#define Config_Bit0 8
#define Config_Bit1 9

//Initialise Registers & Interfaces

void setup() {
  //Initialise UARTs
  Serial.begin(19200);						//Start hardware UART & set registers for 19200 Baud
  //Set GPIO Registers
  pinMode(Config_Bit0, INPUT);
  pinMode(Config_Bit1, INPUT);
  pinMode(Link_Stat, INPUT);
  pinMode(RX_LED, OUTPUT);
  pinMode(Link_LED, OUTPUT);
  pinMode(Link_Fail, OUTPUT);
  
  // Set output baud rate dependant on Config DIP switch settings
  
  if (digitalRead(Config_Bit0) == 0 && digitalRead(Config_Bit1) == 0){	//Switches 0 0 
    RS422Serial.begin(2400);											//Set NMEA Baud to 2400                      
  }	
  if (digitalRead(Config_Bit0) == 1 && digitalRead(Config_Bit1) == 0){  //Switches 1 0 
    RS422Serial.begin(4800);											//Set NMEA Baud to 4800
  }
  if (digitalRead(Config_Bit0) == 0 && digitalRead(Config_Bit1) == 1){	//Switches 0 1 
    RS422Serial.begin(9600);											//Set NMEA Baud to 9600
  }
  if (digitalRead(Config_Bit0) == 1 && digitalRead(Config_Bit1) == 1){	//Switches 1 1 		
    RS422Serial.begin(19200);											//Set NMEA Baud to 19200;
  }
}

void loop() {						   //Function will loop continuoisly to check link status and contents of fibre UART input buffer
  if (digitalRead(Link_Stat) == 0 ) {  //Link Status 'LOW' detected - link down
    digitalWrite(Link_LED, LOW);	   //Disable LED Link 'ok' indication
    digitalWrite(Link_Fail, HIGH);	   //Set Link fault output 'HIGH' - LED + Relay
  }
  else {							   //Link status other than 'LOW' detected
    digitalWrite(Link_LED, HIGH);	   //Enable LED Link 'ok' indication
    digitalWrite(Link_Fail, LOW);	   //Set Link fault output 'LOW' - LED + Relay
  }
  while (Serial.available() > 0) {	   //Will check contents of fibre UART input buffer, if any data is in the buffer -> enter loop
    digitalWrite(RX_LED, HIGH);		   //Set Rx LED inidcation 'HIGH'
    rx_byte = Serial.read();		   //Read contents of Fibre UART input buffer at 19200 baud and place contents into rx_byte
    RS422Serial.print(rx_byte);		   //Re-transmit rx_byte out the software UART to the max485s at the configured baud rate 
    }
   digitalWrite(RX_LED, LOW);		   //If not in the reciving loop, set Rx LED indication 'LOW'
   }
